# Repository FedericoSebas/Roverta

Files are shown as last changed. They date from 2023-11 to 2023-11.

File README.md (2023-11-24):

## Rover de Exploración

Este proyecto se centra en un rover de exploración que se divide en dos secciones principales: el controlador de motores y la estación meteorológica.

### Controlador de Motores

El controlador de motores es responsable de la locomoción del rover. Permite al rover moverse y navegar por su entorno.

### Estación Meteorológica

La estación meteorológica es controlada por un ESP32 y utiliza varios sensores para recopilar datos sobre el entorno. Los sensores incluyen:

- **Fotodiodo y LDR (Resistencia Dependiente de la Luz)**: Estos son sensores analógicos que miden la intensidad de la luz. El fotodiodo es sensible a la luz visible y cercana al infrarrojo, mientras que el LDR cambia su resistencia en función de la cantidad de luz que recibe.

- **DHT22**: Este es un sensor digital de temperatura y humedad. Puede medir temperaturas entre -40 y 80 grados Celsius, y humedad relativa entre 0 y 100%.

- **BMP280**: Este es un sensor digital que puede medir la presión barométrica y la temperatura. La presión barométrica se puede utilizar para calcular la altitud, lo que puede ser útil para determinar la posición del rover.

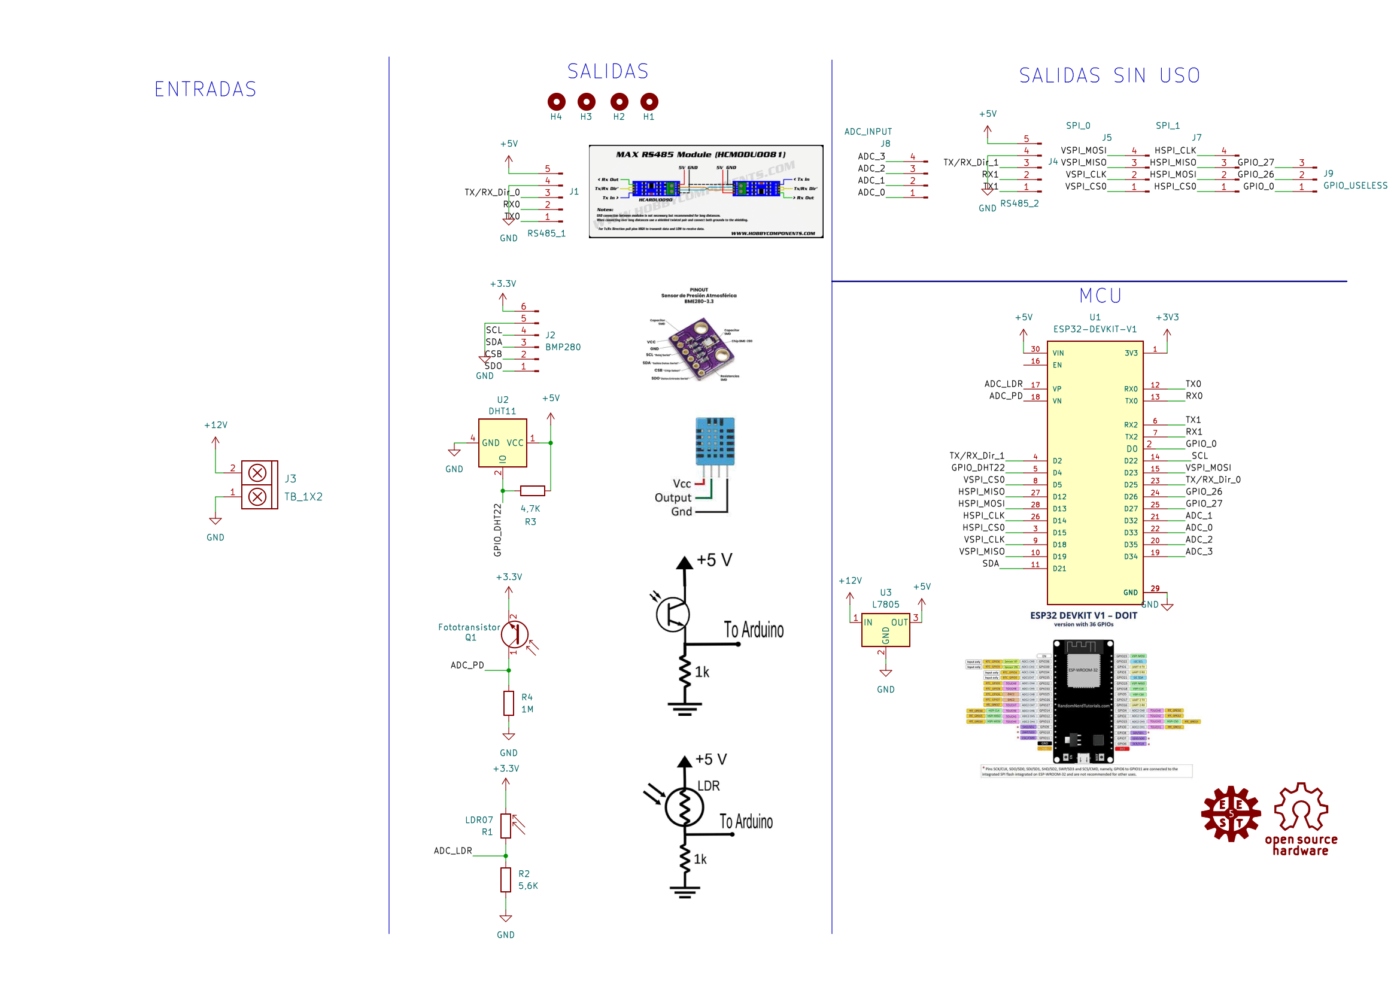
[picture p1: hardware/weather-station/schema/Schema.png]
Diagrama del Rover


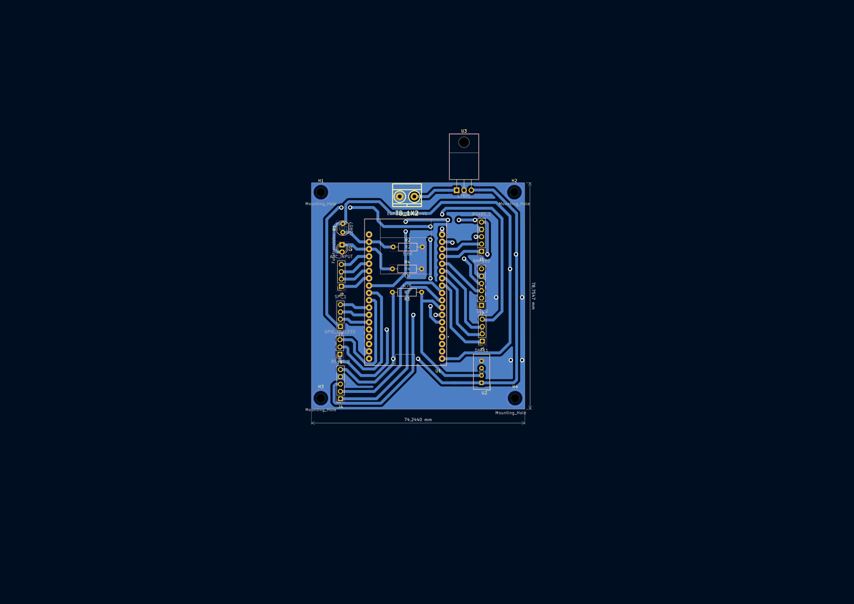
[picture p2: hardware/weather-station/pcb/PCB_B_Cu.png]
PCB del Rover Capa B


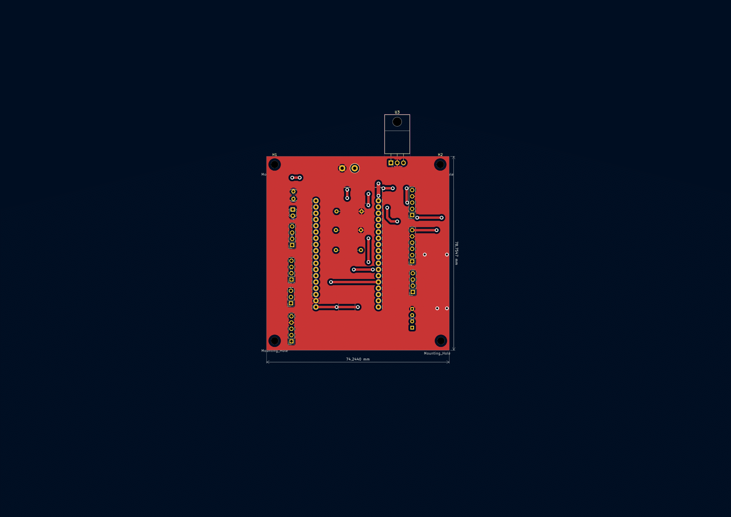
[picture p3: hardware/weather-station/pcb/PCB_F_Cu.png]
PCB del Rover Capa F


## Software

El software proporcionado incluye la biblioteca MQTT creada por nuestro equipo, así como bibliotecas individuales para cada dispositivo que se relacionan con MQTT. Esto se debe a que cada dispositivo tiene una callback para topicos y suscripciones, por lo que es más claro qué topico está relacionado con cada dispositivo.

Esperamos que este proyecto sea de su interés y le invitamos a explorar más a fondo el código y las funcionalidades del rover.

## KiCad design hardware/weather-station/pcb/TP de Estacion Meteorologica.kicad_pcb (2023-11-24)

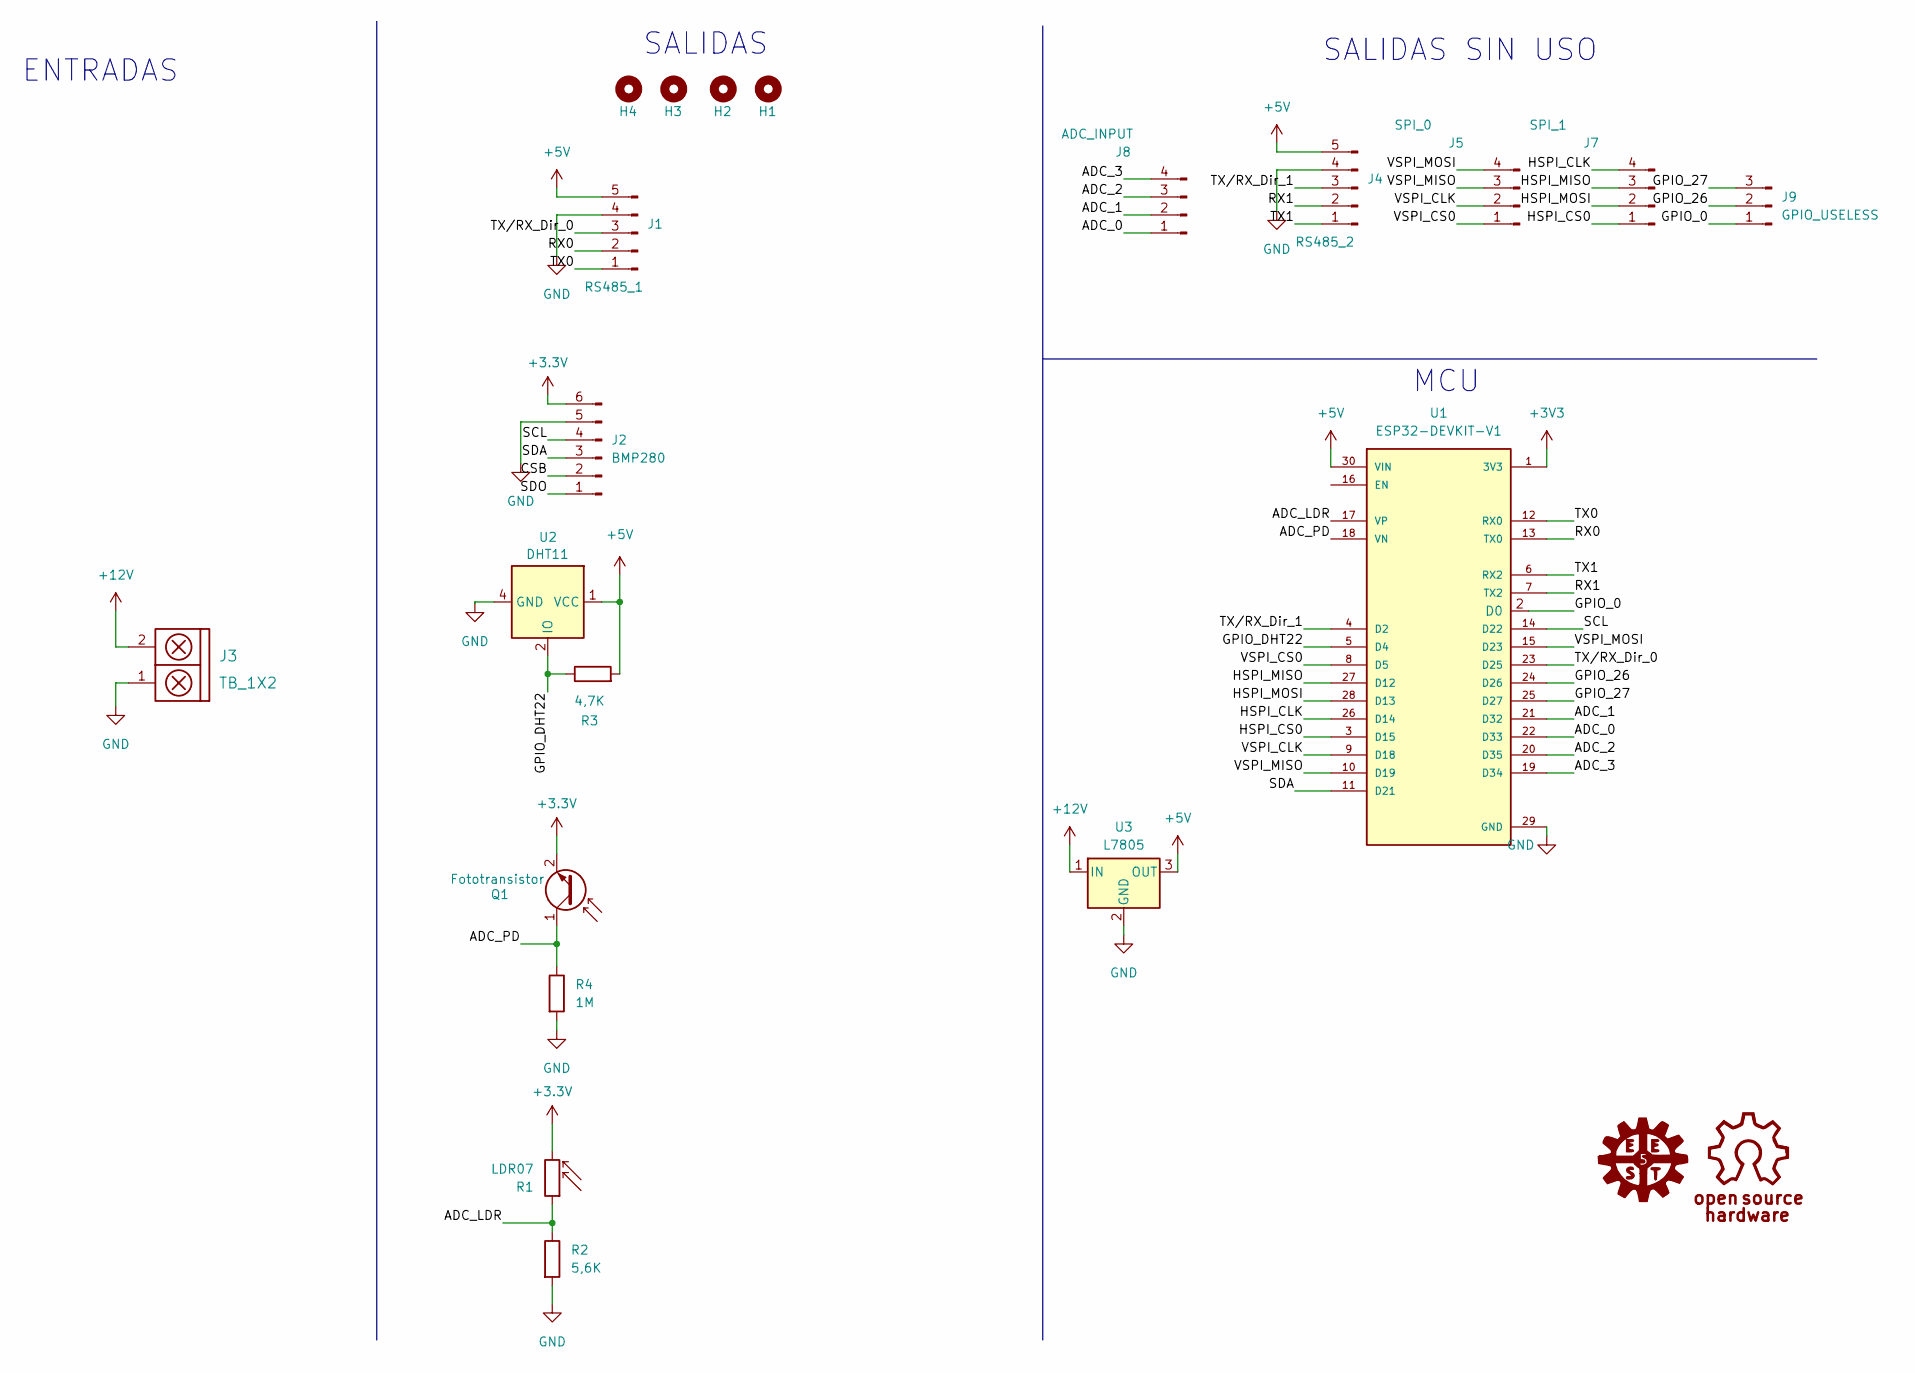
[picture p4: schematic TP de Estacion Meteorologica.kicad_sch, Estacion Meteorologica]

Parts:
H1, H2, H3, H4: Mounting_Hole; MountingHole_3mm
J1: RS485_1; PinSocket_1x05_P2.54mm_Vertical
J2: BMP280; PinSocket_1x06_P2.54mm_Vertical
J3: TB_1X2; BORNERA2_AZUL
J4: RS485_2; PinSocket_1x05_P2.54mm_Vertical
J5: SPI_0; PinSocket_1x04_P2.54mm_Vertical
J7: SPI_1; PinSocket_1x04_P2.54mm_Vertical
J8: ADC_INPUT; PinSocket_1x04_P2.54mm_Vertical
J9: GPIO_USELESS; PinSocket_1x03_P2.54mm_Vertical
Q1: Fototransistor; LED_D3.0mm_FlatTop
R1: LDR07; R_LDR_5.0x4.1mm_P3mm_Vertical
R2: 5,6K; R_Axial_DIN0207_L6.3mm_D2.5mm_P10.16mm_Horizontal
R3: 4,7K; R_Axial_DIN0207_L6.3mm_D2.5mm_P10.16mm_Horizontal
R4: 1M; R_Axial_DIN0207_L6.3mm_D2.5mm_P10.16mm_Horizontal
U1: ESP32-DEVKIT-V1; MODULE_ESP32_DEVKIT_V1; PARTREV N/A
U2: DHT11; Aosong_DHT11_5.5x12.0_P2.54mm
U3: L7805; TO-220-3_Horizontal_TabDown

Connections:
+5V: J1.5, J4.5, R3.2, U1.30 (VIN), U2.1 (VCC), U3.3 (OUT)
+12V: J3.2, U3.1 (IN)
/ADC_0: J8.1, U1.22 (D33)
/ADC_1: J8.2, U1.21 (D32)
/ADC_2: J8.3, U1.20 (D35)
/ADC_3: J8.4, U1.19 (D34)
/ADC_LDR: R1.1, R2.1, U1.17 (VP)
/ADC_PD: Q1.1 (C), R4.1, U1.18 (VN)
/CSB: J2.2
/GPIO_0: J9.1, U1.2 (D0)
/GPIO_26: J9.2, U1.24 (D26)
/GPIO_27: J9.3, U1.25 (D27)
/GPIO_DHT22: R3.1, U1.5 (D4), U2.2 (IO)
/HSPI_CLK: J7.4, U1.26 (D14)
/HSPI_CS0: J7.1, U1.3 (D15)
/HSPI_MISO: J7.3, U1.27 (D12)
/HSPI_MOSI: J7.2, U1.28 (D13)
/RX0: J1.2, U1.13 (TX0)
/RX1: J4.2, U1.7 (TX2)
/SCL: J2.4, U1.14 (D22)
/SDA: J2.3, U1.11 (D21)
/SDO: J2.1
/TX0: J1.1, U1.12 (RX0)
/TX1: J4.1, U1.6 (RX2)
/TX/RX_Dir_0: J1.3, U1.23 (D25)
/TX/RX_Dir_1: J4.3, U1.4 (D2)
/VSPI_CLK: J5.2, U1.9 (D18)
/VSPI_CS0: J5.1, U1.8 (D5)
/VSPI_MISO: J5.3, U1.10 (D19)
/VSPI_MOSI: J5.4, U1.15 (D23)
GND: J1.4, J2.5, J3.1, J4.4, R2.2, R4.2, U1.29 (GND), U2.4 (GND), U3.2 (GND)

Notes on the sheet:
ENTRADAS
SALIDAS
MCU
SALIDAS SIN USO

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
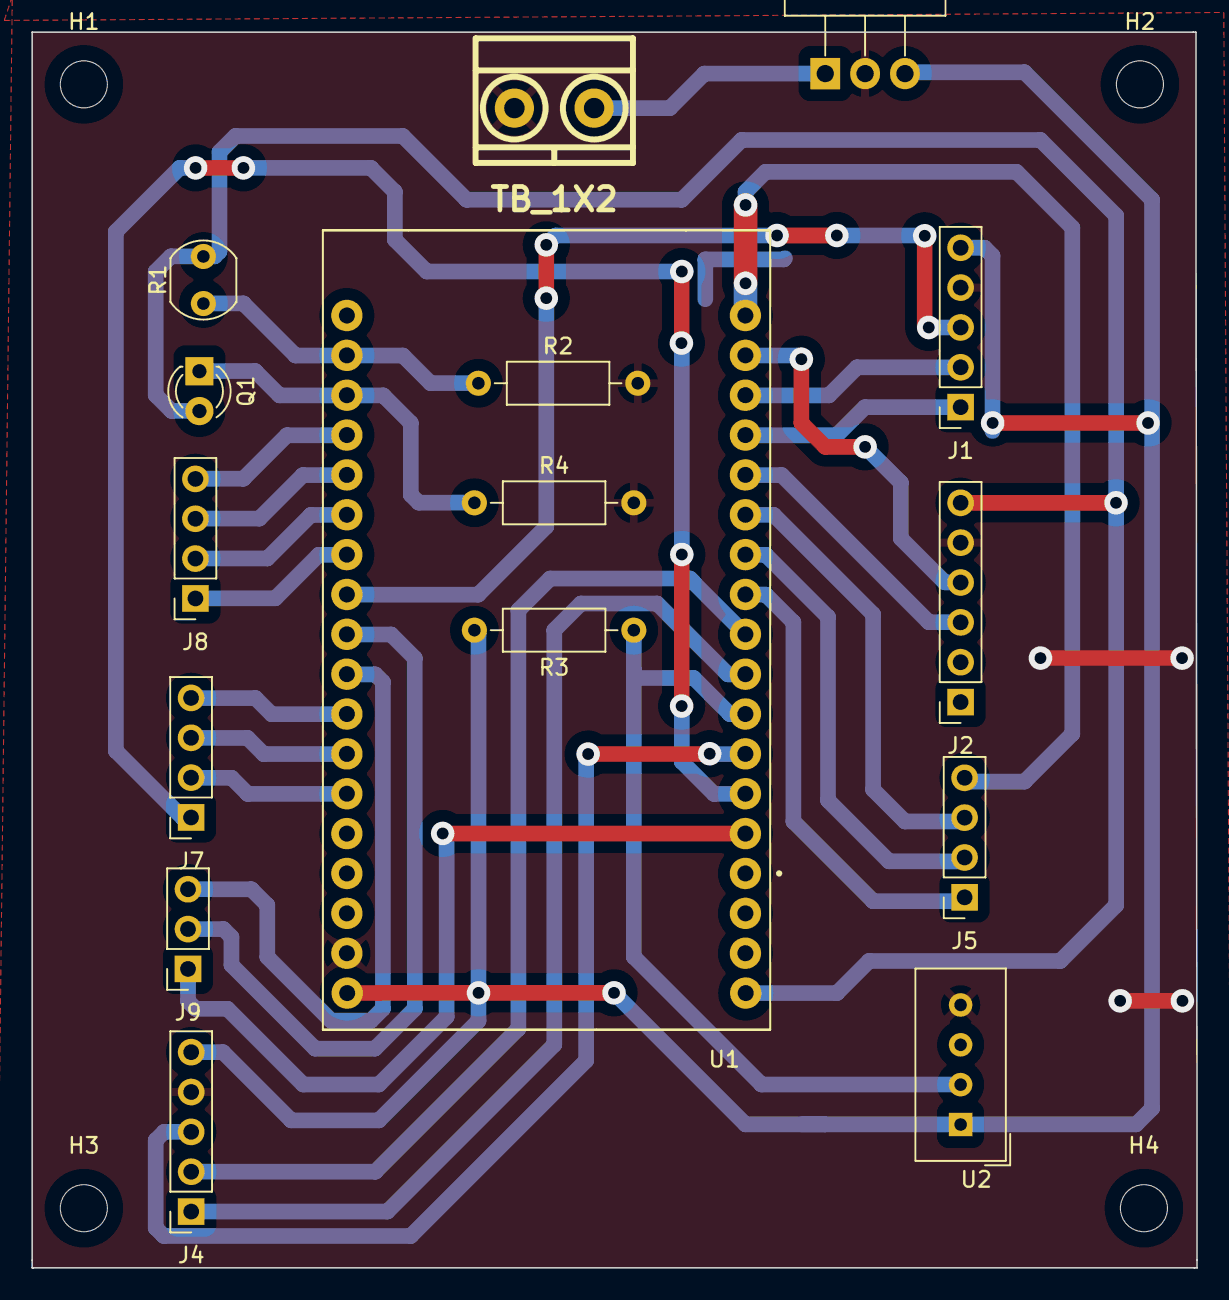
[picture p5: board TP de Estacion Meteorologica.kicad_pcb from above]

Board: 2 copper layers, 74.2 x 78.8 mm, 20 parts (0 on the bottom side), 30 nets.

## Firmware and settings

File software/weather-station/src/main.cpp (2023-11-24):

// From https://randomnerdtutorials.com/esp32-mqtt-publish-subscribe-arduino-ide

#include "Arduino.h"
#include <WiFiClientSecure.h>
#include "Mqtt.h"
#include "BMP280.h"
#include "DHT22.h"
#include "LDR.h"
#include "PD.h"
#include "WiFiKeys.h"
#include <PubSubClient.h>
#include "WiFiClientSecure.h"
#include "env.h"
#include "WiFiKeys.h"

#define LDR_PIN 36
#define PD_PIN 39
#define DHT22_PIN 4

WiFiClient espClient;
Mqtt client(espClient);

void wifiConnect()
{
  delay(10);
  Serial.println();
  Serial.print("Connecting to ");
  Serial.println(ssid);
  WiFi.mode(WIFI_STA);
  WiFi.begin(ssid, password);
  while (WiFi.status() != WL_CONNECTED)
  {
    delay(500);
    Serial.print(".");
  }
  Serial.println("");
  Serial.println("WiFi connected");
  Serial.println("IP address: ");
  Serial.println(WiFi.localIP());
  Serial.println(WiFi.macAddress());
}

Sensor *ldr = new LDR(client, LDR_PIN);
Sensor *pd = new PD(client, PD_PIN);
Sensor *dht = new SensorDHT22(client, DHT22_PIN);
Sensor *bmp = new BMP280(client);

void CallbackTopic(char *topic, byte *message, unsigned int length)
{
  ldr->callbackTopic(topic, message, length);
  pd->callbackTopic(topic, message, length);
  dht->callbackTopic(topic, message, length);
  bmp->callbackTopic(topic, message, length);
}

void CallbackSubscribe()
{
  ldr->callbackSubscribe();
  pd->callbackSubscribe();
  dht->callbackSubscribe();
  bmp->callbackSubscribe();
}


void setup() {
  Serial.begin(115200);
  randomSeed(analogRead(13));
  client.setCallback(CallbackTopic);
  client.setCallbackSubscribe(CallbackSubscribe);
  wifiConnect();
}

void loop() {
  client.reconnect();
  client.loop();
  ldr->measure();
  pd->measure();
  bmp->measure(ALL);
  dht->measure(ALL);
  
  ldr->publishMeasurement(1000);
  pd->publishMeasurement(1000);
  bmp->publishMeasurement(ALL,1000);
  dht->publishMeasurement(ALL,1000);
}

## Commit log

2023-08-29 weather station and mqtt src code for esp32
2023-09-25 add enum magnitudes in Sensor.h
2023-11-24 ready to merge
    [TP de Estacion Meteorologica.kicad_pcb, TP de Estacion Meteorologica.kicad_sch]
